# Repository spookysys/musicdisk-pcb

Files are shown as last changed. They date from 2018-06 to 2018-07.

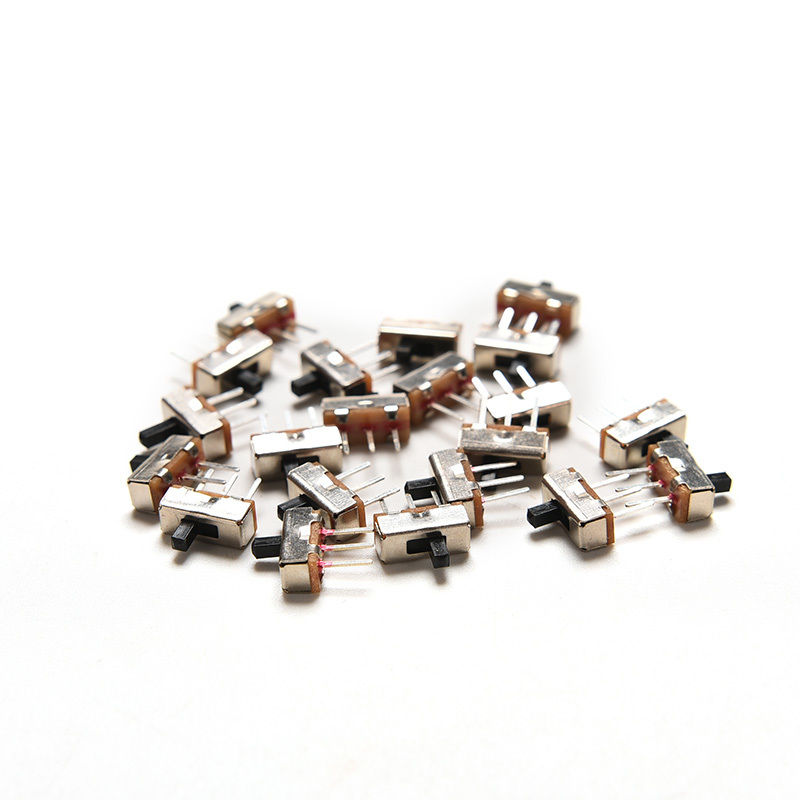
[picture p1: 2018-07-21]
components/spdt_microswitches.jpg

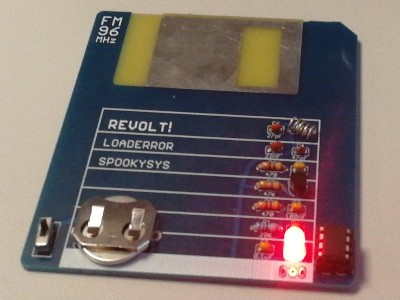
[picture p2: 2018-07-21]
musicdisk.jpg

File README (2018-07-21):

This describes how to build these boards.

SHOPPING LIST

Components - see components subfolder
Also get a socket for the ATtiny, you don't really want to solder it in place
Wire for the little coil - see specs in components file 
PCBs - render with Eagle and order for ~ $5 from Seeed Studio
ATtiny programmer - see https://www.sparkfun.com/products/11801

Notes:
* Must be the 20Mhz version of the ATtiny. Still not really guaranteed to work, as we are overclocking to 32MHz but haven't seen any
  issues.
* The little coil must be the right wire diameter, number of turns, coil diameter. You're likely to overshoot the 96MHz frequency printed
  on the board. Press the coil together to reduce the frequency until you're at 96MHz.
* The battery must be the rechargeable LIR2032 type. The usual non-rechargeable CB2032 doesn't have enough wattage.

HOW TO MAKE

1. Open project in Eagle.
2. Follow tutorial on Seeed studio for their most basic cards (they have a prototype program for around $5 for 10 cards), and order the
   cards.
3. Buy the components and the rest from shopping list above.
4. Make a coil by turning wire around a screwdriver of the right size. Look at the photo.
5. Solder everything.
6. Program the included synth.hex to your ATtiny as described below. Set fuses then upload build.
7. Insert LIR2032 battery and turn the unit on, LED should light up. After 3 minutes when the song is over it should blink.
8. Search for the signal on your rado. Press the coil together until you hit 96 MHz.

PROGRAM

Hoe to program the ATtiny using avrdude and usbtiny programmer

# Set fuses to defaults (not required)
avrdude -c usbtiny -p attiny85 -U lfuse:w:0x62:m -U hfuse:w:0xdf:m -U efuse:w:0xff:m

# Set 16mhz clock and other required fuses
avrdude -c usbtiny -p attiny85 -U lfuse:w:0xe1:m -U hfuse:w:0xdf:m -U efuse:w:0xff:m

# Upload binary
avrdude -c usbtiny -p attiny85 -U flash:w:synth.hex

CONTACT

spookysys at gmail

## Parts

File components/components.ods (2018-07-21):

Components
Symbol | What | Value | Marking
Q1 | Transistor | BC547 | BC547
C1 | Capacitor | 100nF | 104
C2 | Capacitor | 100nF | 104
C3 | Capacitor | 1nF | 102
C4 | Capacitor | 47pF | 47
C5 | Capacitor | 5.6pF | 5.6
C6 | Capacitor | 27pF | 27
C7 | Capacitor | 22nF | 223
R1 | Resistor | 4.7K
R2 | Resistor | 470
R3 | Resistor | 47K
R4 | Resistor | 470
L1 | Inductor | ?? AWG, 5.5 turns, ?? coil radius (TODO)
LED1 | LED | 5mm red
IC1 | Micro | ATTiny85 20MHz | PU20
S1 | Switch | SPDT microswitches from ebay (see photo)
G1 | Batteryholder | BK-913
 | Battery | LIR2032 | * NOTE non-rechargeable CR2032 batteries won’t work!

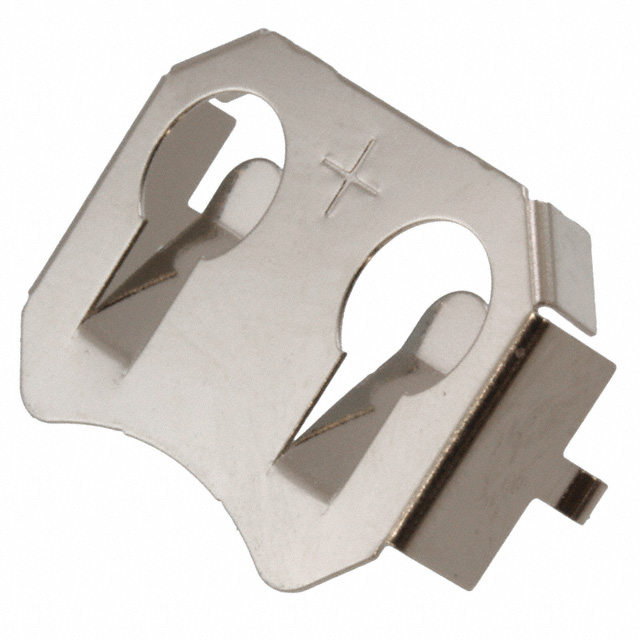
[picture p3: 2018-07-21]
components/BK-913.JPG

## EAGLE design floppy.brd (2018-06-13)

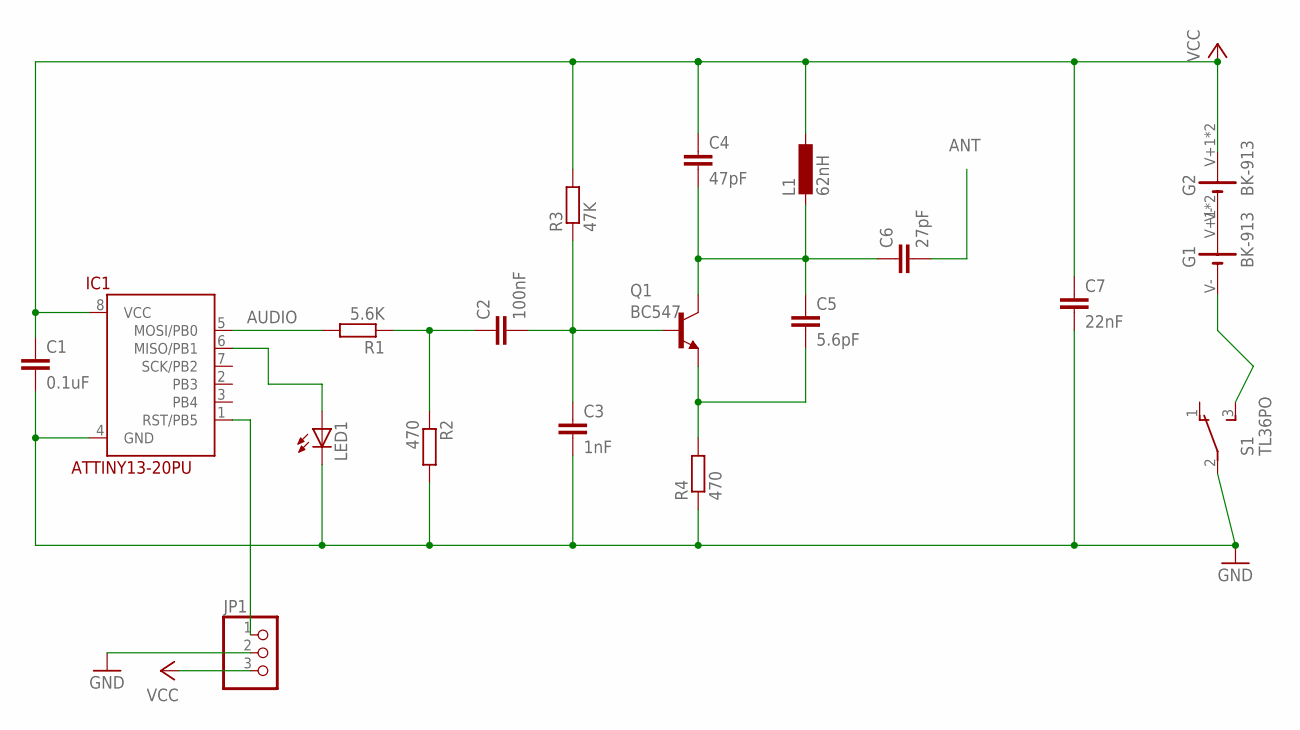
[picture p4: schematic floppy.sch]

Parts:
C1: 0.1uF; C025-025X050
C2: 100nF; C025-025X050
C3: 1nF; C025-025X050
C4: 47pF; C025-025X050
C5: 5.6pF; C025-025X050
C6: 27pF; C025-025X050
C7: 22nF; C025-025X050
G1, G2: BK-913
IC1: ATTINY13-20PU; DIL08
JP1: PINHD-1X3; 1X03
L1: 62nH; 0207/7
LED1: LED5MM
Q1: BC547; TO92
R1: 5.6K; 0207/7
R2, R4: 470; 0207/7
R3: 47K; 0207/7
S1: TL36PO; TL3XPO

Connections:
ANT: C6.2
AUDIO: C2.1, R1.1, R2.1
DW: IC1.1 (RST/PB5), JP1.1
GND: C1.2, C3.2, C7.2, IC1.4 (GND), JP1.2, LED1.K (C), R2.2, R4.1, S1.2
unnamed: G1.V-, S1.3 (S)
unnamed: IC1.5 (MOSI/PB0), R1.2
unnamed: IC1.6 (MISO/PB1), LED1.A
unnamed: C4.2, C5.1, C6.1, L1.2, Q1.3 (C)
unnamed: C5.2, Q1.1 (E), R4.2
unnamed: C2.2, C3.1, Q1.2 (B), R3.1
unnamed: G1.V+1 (V+), G1.V+2 (V+), G2.V-
VCC: C1.1, C4.1, C7.1, G2.V+1 (V+), G2.V+2 (V+), IC1.8 (VCC), JP1.3, L1.1, R3.2

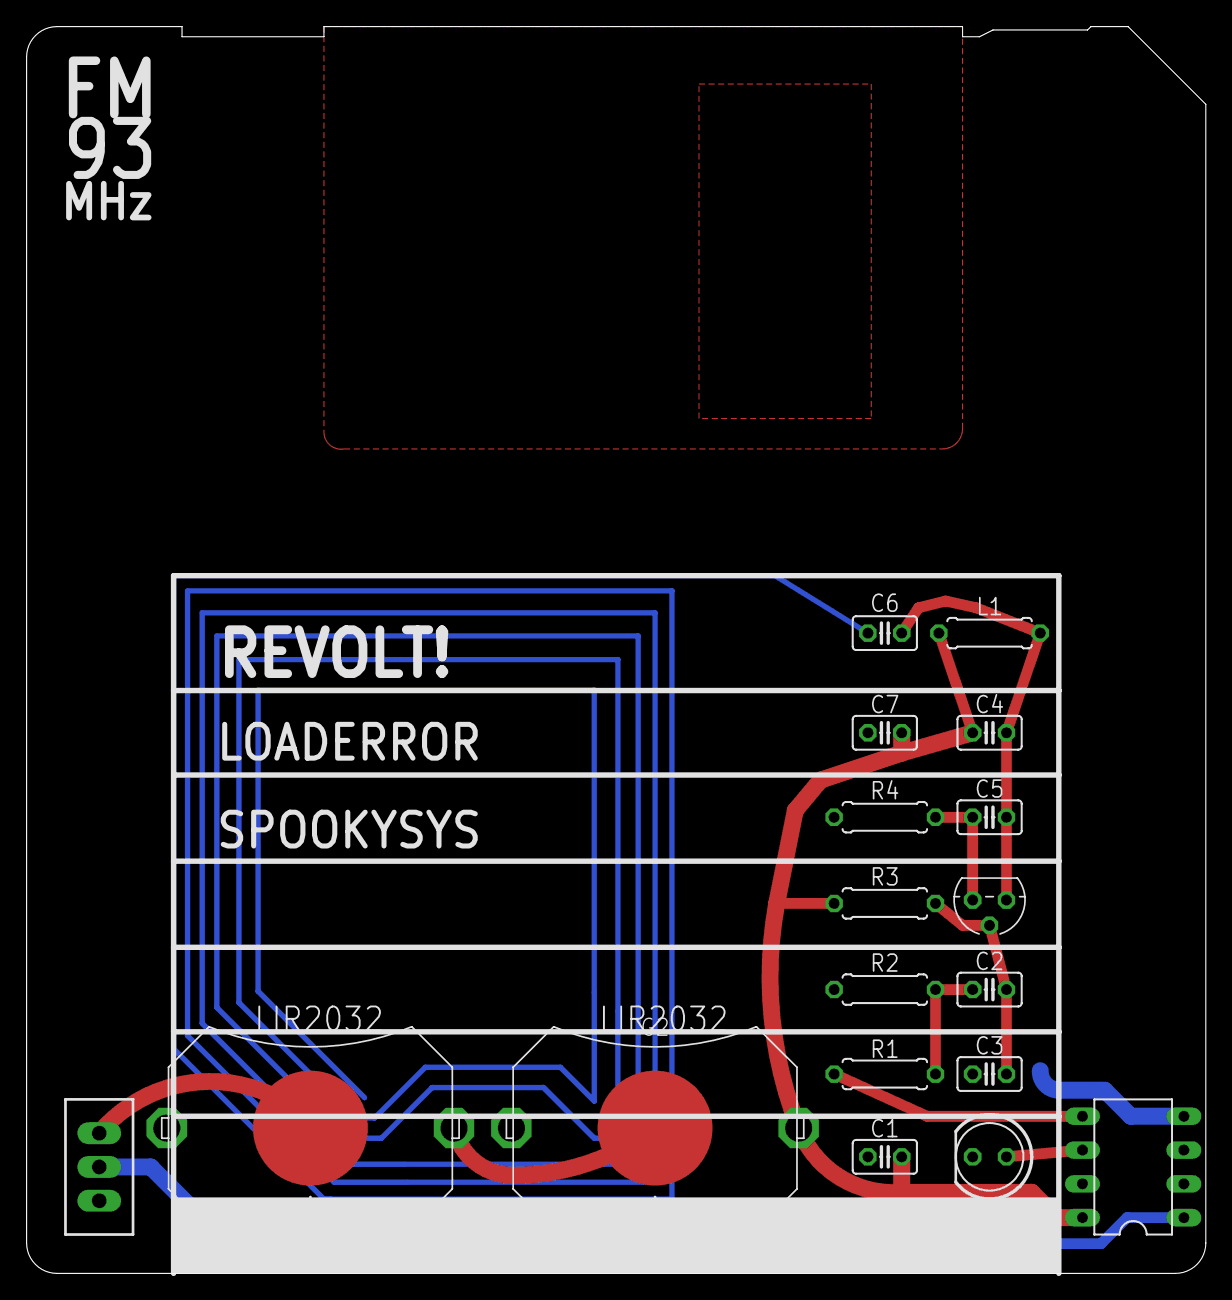
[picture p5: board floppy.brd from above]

Board: 2 copper layers, 88.6 x 93.7 mm, 19 parts (0 on the bottom side), 11 nets.

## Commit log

2017-01-31 Moved synth to a separate repository
    [floppy.brd, floppy.sch]
2017-02-17 Made layout much nicer LED now driven directly from AVR TODO: * check that LED can be driven driectly from AVR * pirate flag and nicer "illegal radio transmitter" text * adjust FM frequency text * ch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
    [floppy.brd, floppy.sch]
2017-02-21 Fixed battery holder footprint Added "Illegal radio transmitter"
    [floppy.brd, floppy.sch]
2017-02-21 Added warnings and skull
    [floppy.brd]
2017-02-21 More aesthetics
    [floppy.brd]
2017-02-21 Added bottom silkscreen, as dirtypcbs supports it after all
    [floppy.brd]
2017-05-22 New circuit that has been tested to work up front
    [floppy.brd, floppy.sch]
2017-05-23 Ordered this
    [floppy.brd]
2017-08-27 Changed to 96HZ, added circle on back
    [floppy.brd, floppy.sch]
2017-08-30 Changed to through-hole AVR Shortened antenna to match 96MHz
    [floppy.brd, floppy.sch]
2018-05-15 Added list of components, stock, and how many ordered
    [components.ods]
2018-05-16 components: changed
    [components.ods]
2018-05-30 Changed R1 to 4.7K ohm, which gives much louder sound.
    [floppy.brd, floppy.sch]
2018-06-13 Now two batteries Added inductor size too and other minor fixes
    [floppy.brd, floppy.sch]
2018-06-13 Set right L-value
    [floppy.brd]
2018-07-21 Updates to components list
    [components.ods]
